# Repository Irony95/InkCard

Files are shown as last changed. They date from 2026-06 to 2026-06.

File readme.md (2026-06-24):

# Introduction
An e-ink display card that mirrors your phone screen, to help with reading documents, e-books, web pages etc!

The project is made to be as cheap as possible, coming to a total cost of around $35USD for materials. This would be even lower if made/bought in bulk!

As this is a prototype and in heavy development, I would not recommend making this unless you're willing to tinker/is familiar with electronics and or app dev.
Nevertheless, If you do want to make the project you are free to do so! I am open to answering any questions should you make the card.
I am also open to the idea of making and selling the hardware itself, though this comes down to if there is interest in the project and when I feel the quality is good enough.

Currently, there is only support for an android app. Check out the repo [here](https://github.com/Irony95/InkCard-androidApp).
I have no experience in IOS development, so I am entirely unsure if an app can even be made for the IOS system. If it is, do let me know!

Any suggestions and support is greatly welcomed.

### Notes when building
1. Use a 11uH receiver coil and connect to AC1 and AC2. feel free to use a different coil if you so wish, with C32-C34 and C15 for tuning. refer to BQ51013 datasheet for more info
2. Bridge both JP1 and JP3 from the middle to pad 3, these help select options for the e-paper driver
3. Adjust/remake the CoilLifter.stl to fit your receiver coil size

### Glam Pics!





### Future 
Although the project was primarily built to be as cheap as possible so to allow anybody to get an e-reader, a future version with touch screen and battery is being considered! This version would likely add significant amounts to the cost, but would likely make the project infinitely better. 
Additional features like auto/partial screen refreshes, manual cropping, custom button functions are also being considered.

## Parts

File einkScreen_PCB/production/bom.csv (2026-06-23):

Designator | Footprint | Quantity | Value | LCSC Part #
C1, C16, C17, C18, C29, C31, C33 | 0805 | 7 | 100nF | C28233
C10, C11, C2, C20, C3, C4, C5, C6, C7, C8, C9 | 0805 | 11 | 1uF | C28323
C12, C13, C27 | 0805 | 3 | 4.7uF | C1779
C14, C19, C28, C30 | 0805 | 4 | 10uF | C15850
C15 | 0805 | 1 | 2.2nF | C28260
C21, C22 | 0805 | 2 | 10nF | C1710
C23, C24 | 0805 | 2 | 470nF | C13967
C25, C26, C34 | 0805 | 3 | 22nF | C1729
C32 | 0805 | 1 | 33nF | C1739
D1, D2, D3 | D_SOD-123 | 3 | MBR0530 | C18863
D4 | 0805 | 1 | LED | C84256
D5 | D_SOD-123 | 1 | 1N5819 | C82544
D6, D7, D8 | D_SOD-923 | 3 | ESD9B5.0ST5G | C111566
J3 | HRS_FH34SRJ-24S-0.5SH_50_ | 1 | FH34SRJ-24S-0.5SH_50_ | C324726
JP2 | TestPoint_2Pads_Pitch2.54mm_Drill0.8mm | 1 | JumperEN
JP4 | TestPoint_2Pads_Pitch2.54mm_Drill0.8mm | 1 | JumperBOOT
L1 | 1210 | 1 | 10uH | C60541
Q1 | TSOT-23 | 1 | A03400 | C20917
Q2, Q4, Q5 | TSOT-23 | 3 | A03401 | C15127
Q3 | TSOT-23 | 1 | S8050 | C2146
R10, R11, R12, R15, R19, R20, R24, R25, R3, R5 | 0805 | 10 | 10K | C17414
R16 | 0805 | 1 | 200 | C17540
R17 | 0805 | 1 | 20K | C4328
R18 | 0805 | 1 | 560R | C28636
R2 | 0805 | 1 | 3R | C17660
R21 | 0805 | 1 | 330R | C17630
R22 | 0805 | 1 | 0R | C17477
R4 | 0805 | 1 | 47K | C17713
R7, R9 | 0805 | 2 | 5.1K | C27834
R8 | 0805 | 1 | 100K | C149504
SW1, SW2 | Panasonic_EVQPUL_EVQPUC | 2 | SW_Push | C79174
TP1 | TestPoint_Pad_D3.0mm | 1 | AC1
TP2 | TestPoint_Pad_D3.0mm | 1 | AC2
U1 | VQFN-20_L4.5-W3.5-P0.50-BL-EP_BQ24100RHLR | 1 | BQ51013BRHLR | C55663
U2 | SOT-23-5 | 1 | XC6220B331MR | C22466451
U3 | WIRELM-SMD_ESP32-C6-WROOM-1 | 1 | ESP32-C6-WROOM-1-N8 | C5366877
USB1 | USB-C-SMD_TYPE-C-16PIN-2MD-073 | 1 | TYPE-C 16PIN 2MD | C2765186

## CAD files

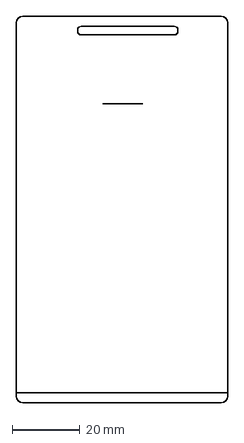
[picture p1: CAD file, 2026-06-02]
einkScreen_PCB/PCBOutline.dxf
62.4 x 113.8 mm

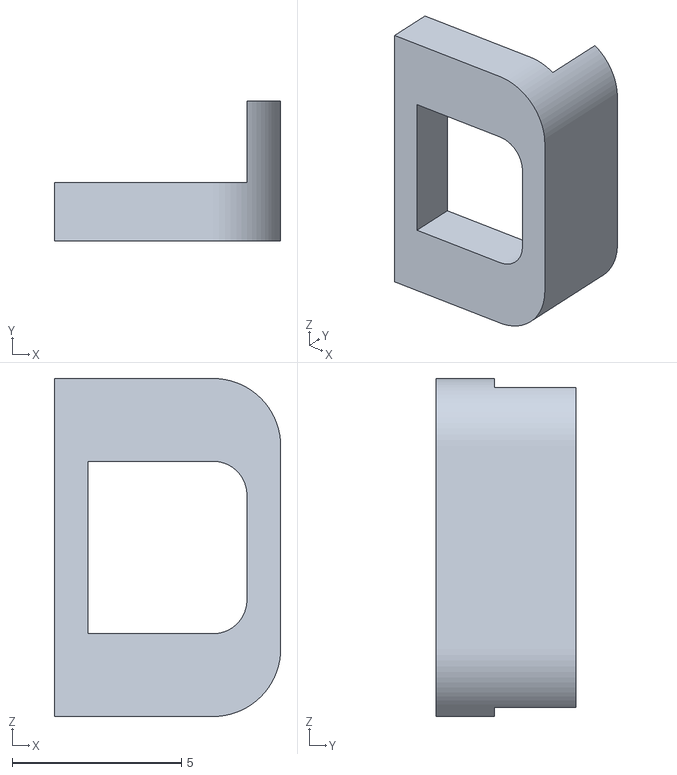
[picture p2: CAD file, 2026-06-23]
inkCard_Case/Button.stl
6.70 x 4.14 x 10.00

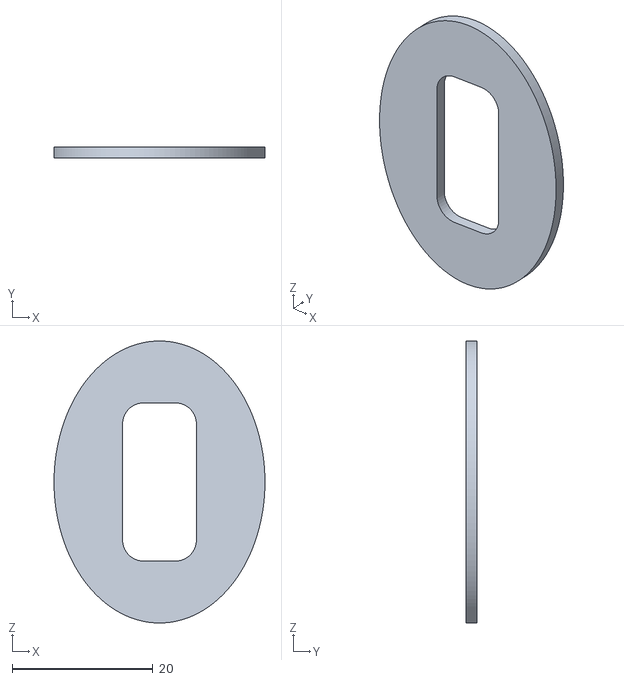
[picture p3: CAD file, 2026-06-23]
inkCard_Case/CoilLifter.stl
30.0 x 1.60 x 40.1

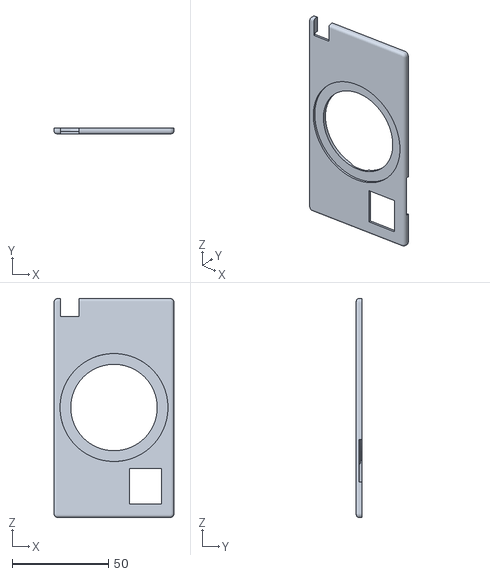
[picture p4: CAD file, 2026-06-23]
inkCard_Case/Body.stl
62.4 x 2.90 x 113.8

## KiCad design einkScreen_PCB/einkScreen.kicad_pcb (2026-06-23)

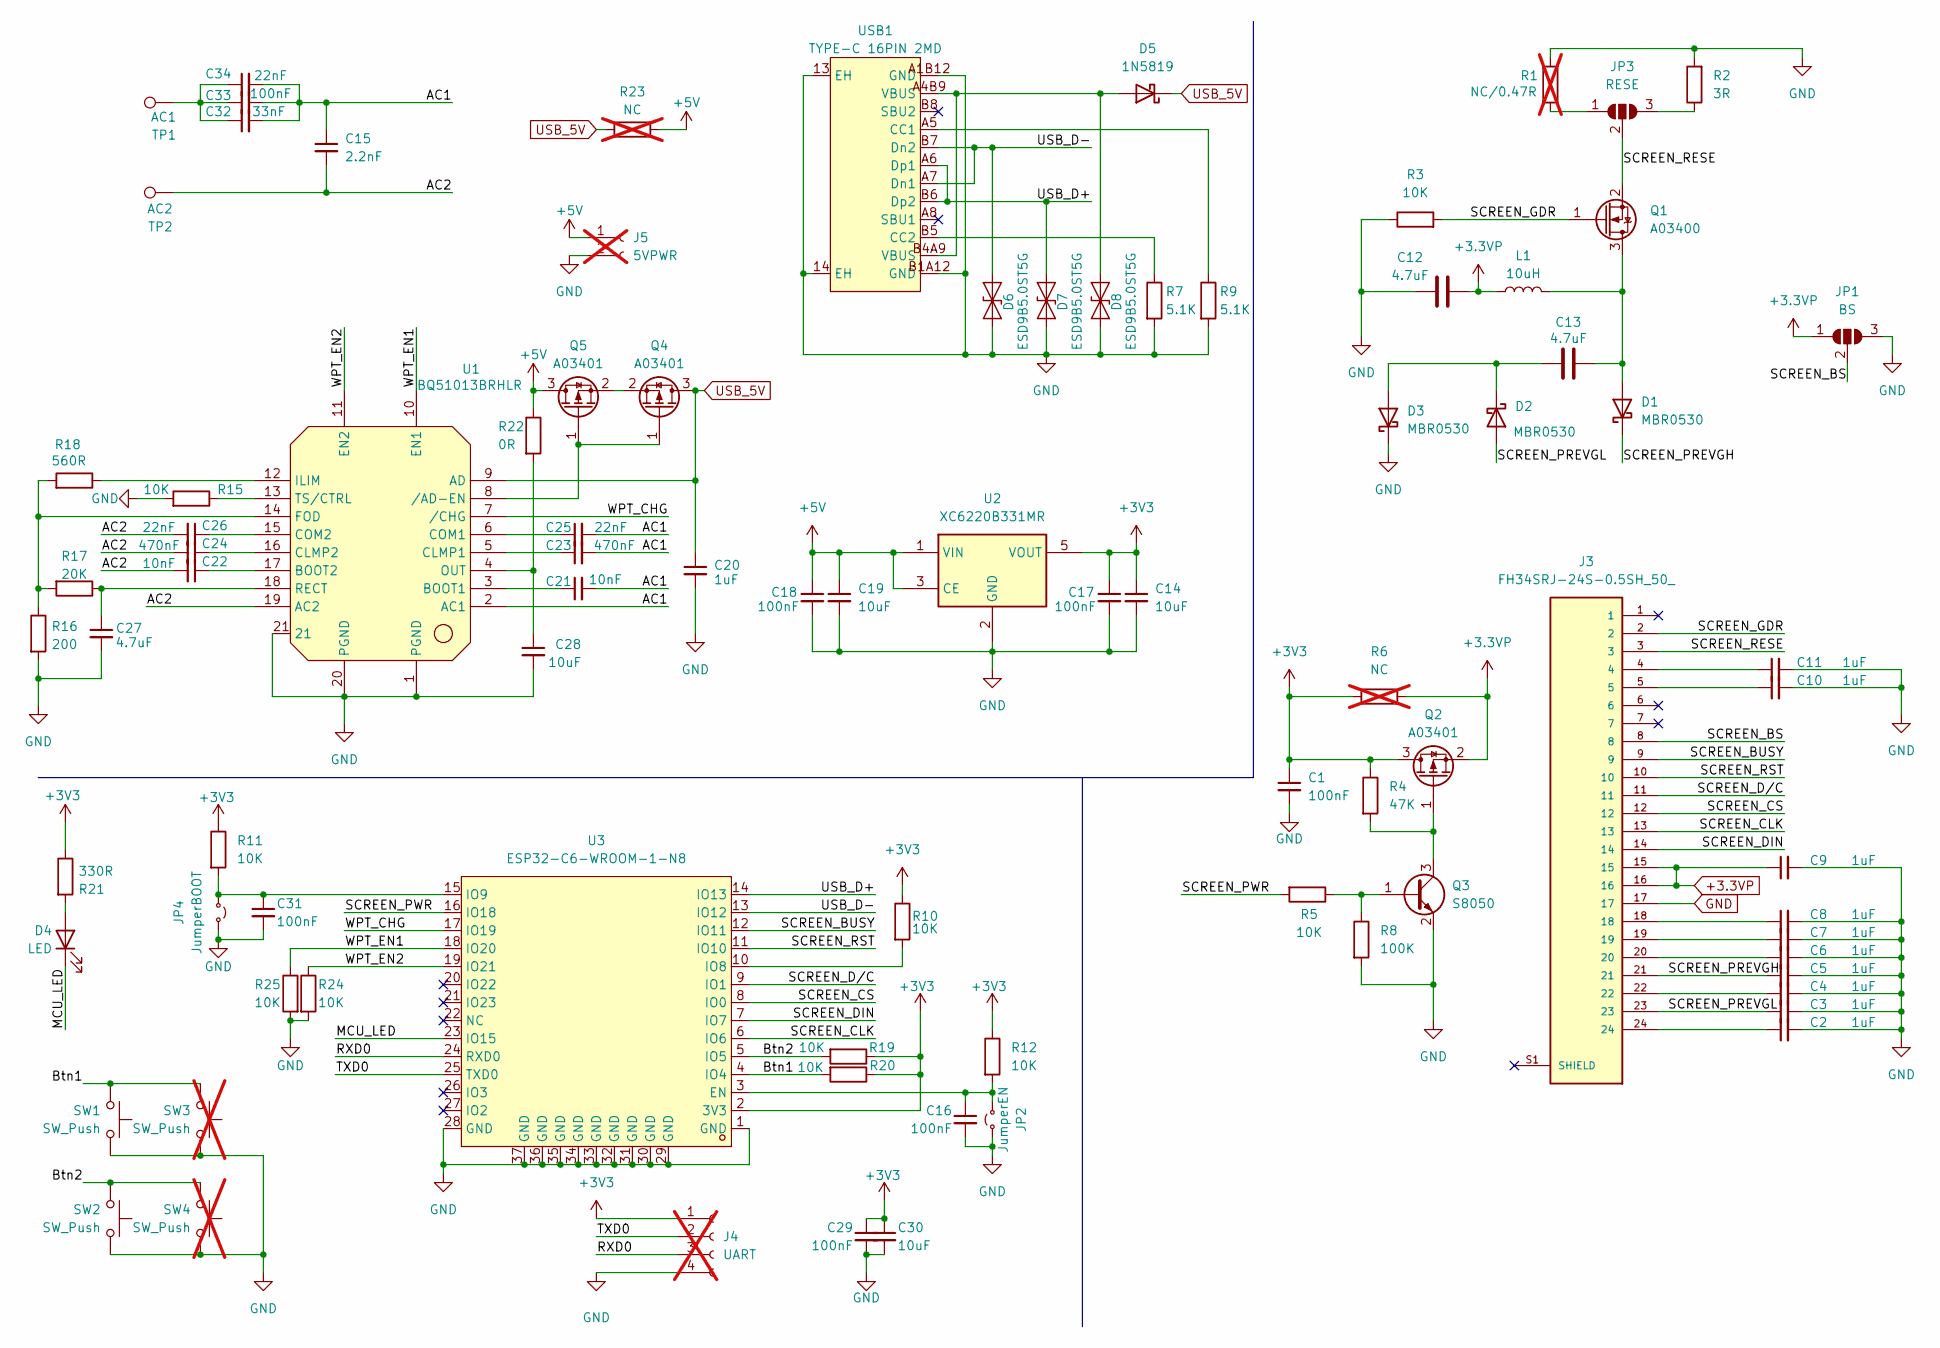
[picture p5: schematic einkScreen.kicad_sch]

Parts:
C1, C16, C17, C18, C29, C31, C33: 100nF; C_0805_2012Metric; LCSC C28233
C2, C3, C4, C5, C6, C7, C8, C9, C10, C11, C20: 1uF; C_0805_2012Metric; LCSC C28323
C12, C13, C27: 4.7uF; C_0805_2012Metric; LCSC C1779
C14, C19, C28, C30: 10uF; C_0805_2012Metric; LCSC C15850
C15: 2.2nF; C_0805_2012Metric; LCSC C28260
C21, C22: 10nF; C_0805_2012Metric; LCSC C1710
C23, C24: 470nF; C_0805_2012Metric; LCSC C13967
C25, C26, C34: 22nF; C_0805_2012Metric; LCSC C1729
C32: 33nF; C_0805_2012Metric; LCSC C1739
D1, D2, D3: MBR0530; D_SOD-123; LCSC C18863
D4: LED; LED_0805_2012Metric; LCSC C84256
D5: 1N5819; D_SOD-123; LCSC C82544
D6, D7, D8: ESD9B5.0ST5G; D_SOD-923; LCSC C111566
J3: FH34SRJ-24S-0.5SH_50_; HRS_FH34SRJ-24S-0.5SH_50_; LCSC C324726
J4: UART; PinSocket_1x04_P2.54mm_Vertical; not fitted
J5: 5VPWR; PinSocket_1x02_P2.54mm_Vertical; not fitted
JP1: BS; SolderJumper-3_P1.3mm_Open_RoundedPad1.0x1.5mm_NumberLabels
JP2: JumperEN; TestPoint_2Pads_Pitch2.54mm_Drill0.8mm
JP3: RESE; SolderJumper-3_P1.3mm_Open_RoundedPad1.0x1.5mm_NumberLabels
JP4: JumperBOOT; TestPoint_2Pads_Pitch2.54mm_Drill0.8mm
L1: 10uH; L_1210_3225Metric; LCSC C60541
Q1: A03400; TSOT-23; LCSC C20917
Q2, Q4, Q5: A03401; TSOT-23; LCSC C15127
Q3: S8050; TSOT-23; LCSC C2146
R1: NC/0.47R; R_0805_2012Metric; not fitted
R2: 3R; R_0805_2012Metric; LCSC C17660
R3, R5, R10, R11, R12, R15, R19, R20, R24, R25: 10K; R_0805_2012Metric; LCSC C17414
R4: 47K; R_0805_2012Metric; LCSC C17713
R6, R23: NC; R_0805_2012Metric; not fitted
R7, R9: 5.1K; R_0805_2012Metric; LCSC C27834
R8: 100K; R_0805_2012Metric; LCSC C149504
R16: 200; R_0805_2012Metric; LCSC C17540
R17: 20K; R_0805_2012Metric; LCSC C4328
R18: 560R; R_0805_2012Metric; LCSC C28636
R21: 330R; R_0805_2012Metric; LCSC C17630
R22: 0R; R_0805_2012Metric; LCSC C17477
SW1, SW2: SW_Push; Panasonic_EVQPUL_EVQPUC; LCSC C79174
SW3, SW4: SW_Push; KEY-SMD_L4.0-W3.0-LS4.9-1; not fitted
TP1: AC1; TestPoint_Pad_D3.0mm
TP2: AC2; TestPoint_Pad_D3.0mm
U1: BQ51013BRHLR; VQFN-20_L4.5-W3.5-P0.50-BL-EP_BQ24100RHLR; MPN BQ51013BRHLR; LCSC Part C55663
U2: XC6220B331MR; SOT-23-5; LCSC C22466451
U3: ESP32-C6-WROOM-1-N8; WIRELM-SMD_ESP32-C6-WROOM-1; MPN ESP32-C6-WROOM-1-N8; LCSC Part C5366877
USB1: TYPE-C 16PIN 2MD; USB-C-SMD_TYPE-C-16PIN-2MD-073; MPN TYPE-C 16PIN 2MD(073); LCSC Part C2765186

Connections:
+3.3VP: C9.1, C12.2, J3.15, J3.16, JP1.1 (A), L1.1, Q2.2 (S), R6.2
+3V3: C1.1, C14.1, C17.1, C29.1, C30.1, J4.1, Q2.3 (D), R4.1, R6.1, R10.1, R11.1, R12.1, R19.1, R20.1, R21.1, U2.5 (VOUT), U3.2 (3V3)
+5V: C18.1, C19.1, J5.1, Q5.3 (D), R22.1, R23.2, U2.1 (VIN), U2.3 (CE)
/AC1: C15.1, C21.2, C23.2, C25.2, C32.2, C33.2, C34.2, U1.2 (AC1)
/AC2: C15.2, C22.2, C24.2, C26.2, TP2.1 (1_1), U1.19 (AC2)
/Btn1: R20.2, SW1.2, SW3.2, U3.4 (IO4)
/Btn2: R19.2, SW2.2, SW4.2, U3.5 (IO5)
/MCU_LED: D4.1 (K), U3.23 (IO15)
/RXD0: J4.3, U3.24 (RXD0)
/SCREEN_BS: J3.8, JP1.2 (C)
/SCREEN_BUSY: J3.9, U3.12 (IO11)
/SCREEN_CLK: J3.13, U3.6 (IO6)
/SCREEN_CS: J3.12, U3.8 (IO0)
/SCREEN_DIN: J3.14, U3.7 (IO7)
/SCREEN_D/C: J3.11, U3.9 (IO1)
/SCREEN_GDR: J3.2, Q1.1 (G), R3.2
/SCREEN_PREVGH: C5.1, D1.1 (K), J3.21
/SCREEN_PREVGL: C3.1, D2.2 (A), J3.23
/SCREEN_PWR: R5.2, U3.16 (IO18)
/SCREEN_RESE: J3.3, JP3.2 (C), Q1.2 (S)
/SCREEN_RST: J3.10, U3.11 (IO10)
/TXD0: J4.2, U3.25 (TXD0)
/USB_D+: D7.2 (A2), U3.14 (IO13), USB1.A6 (Dp1), USB1.B6 (Dp2)
/USB_D-: D6.2 (A2), U3.13 (IO12), USB1.A7 (Dn1), USB1.B7 (Dn2)
/WPT_CHG: U1.7 (/CHG), U3.17 (IO19)
/WPT_EN1: R25.1, U1.10 (EN1), U3.18 (IO20)
/WPT_EN2: R24.1, U1.11 (EN2), U3.19 (IO21)
GND: C1.2, C2.2, C3.2, C4.2, C5.2, C6.2, C7.2, C8.2, C9.2, C10.2, C11.2, C12.1, C14.2, C16.2, C17.2, C18.2, C19.2, C20.2, C27.2, C28.2, C29.2, C30.2, C31.2, D3.1 (K), D6.1 (A1), D7.1 (A1), D8.1 (A1), J3.17, J4.4, J5.2, JP1.3 (B), JP2.2 (B), JP4.2 (B), Q3.2 (E), R1.1, R2.2, R3.1, R7.2, R8.2, R9.2, R15.2, R16.2, R24.2, R25.2, SW1.1, SW2.1, SW3.1, SW4.1, U1.1 (PGND), U1.20 (PGND), U1.21, U2.2 (GND), U3.1 (GND), U3.28 (GND), U3.29 (GND), U3.30 (GND), U3.31 (GND), U3.32 (GND), U3.33 (GND), U3.34 (GND), U3.35 (GND), U3.36 (GND), U3.37 (GND), USB1.13 (EH), USB1.14 (EH), USB1.A1B12 (GND), USB1.B1A12 (GND)
unnamed: C2.1, J3.24
unnamed: C4.1, J3.22
unnamed: C6.1, J3.20
unnamed: C7.1, J3.19
unnamed: C8.1, J3.18
unnamed: C10.1, J3.5
unnamed: C11.1, J3.4
unnamed: C32.1, C33.1, C34.1, TP1.1 (1_1)
unnamed: C13.2, D1.2 (A), L1.2, Q1.3 (D)
unnamed: C13.1, D2.1 (K), D3.2 (A)
unnamed: D4.2 (A), R21.2
unnamed: D5.2 (A), D8.2 (A2), USB1.A4B9 (VBUS), USB1.B4A9 (VBUS)
unnamed: C16.1, JP2.1 (A), R12.2, U3.3 (EN)
unnamed: JP3.1 (A), R1.2
unnamed: JP3.3 (B), R2.1
unnamed: C31.1, JP4.1 (A), R11.2, U3.15 (IO9)
unnamed: Q2.1 (G), Q3.3 (C), R4.2
unnamed: Q3.1 (B), R5.1, R8.1
unnamed: Q4.1 (G), Q5.1 (G), U1.8 (/AD-EN)
unnamed: Q4.2 (S), Q5.2 (S)
unnamed: C21.1, U1.3 (BOOT1)
unnamed: C22.1, U1.17 (BOOT2)
unnamed: C23.1, U1.5 (CLMP1)
unnamed: C24.1, U1.16 (CLMP2)
unnamed: C25.1, U1.6 (COM1)
unnamed: C26.1, U1.15 (COM2)
unnamed: R16.1, R17.2, R18.2, U1.14 (FOD)
unnamed: R18.1, U1.12 (ILIM)
unnamed: C28.1, R22.2, U1.4 (OUT)
unnamed: C27.1, R17.1, U1.18 (RECT)
unnamed: R15.1, U1.13 (TS/CTRL)
unnamed: R10.2, U3.10 (IO8)
unnamed: R9.1, USB1.A5 (CC1)
unnamed: R7.1, USB1.B5 (CC2)
USB_5V: C20.1, D5.1 (K), Q4.3 (D), R23.1, U1.9 (AD)

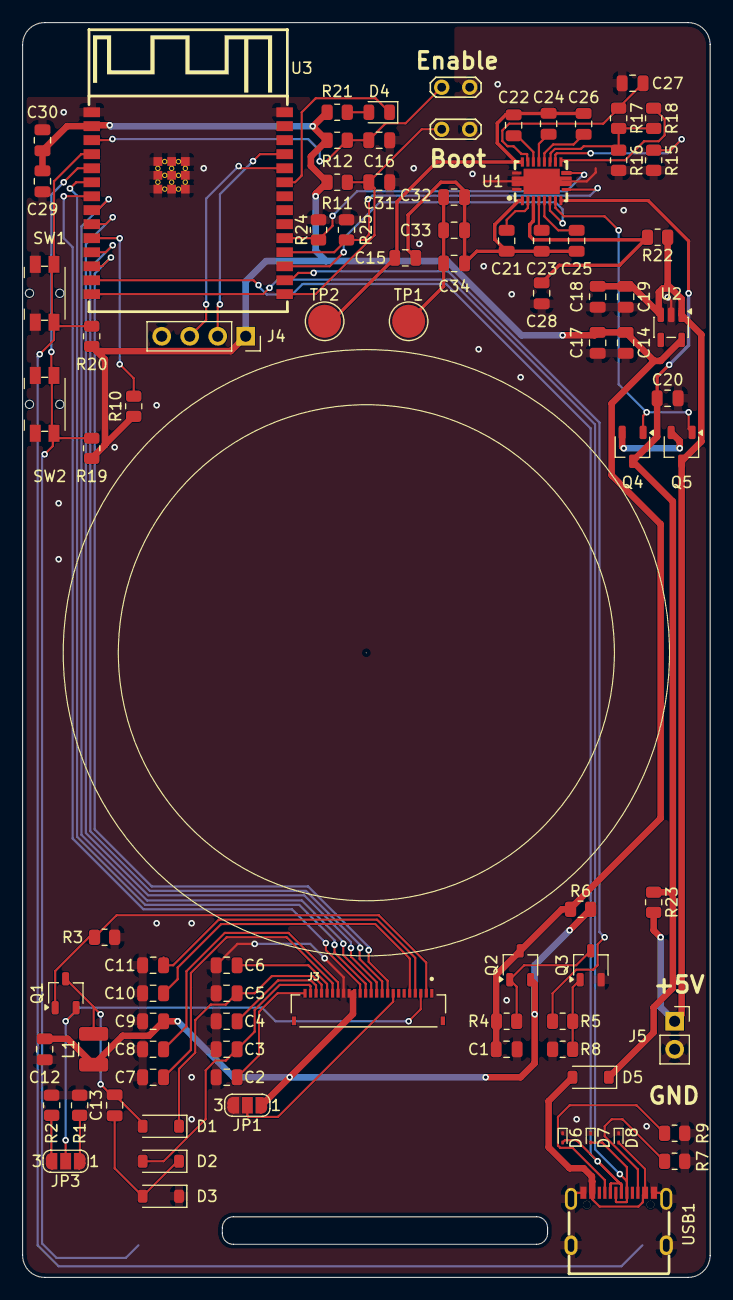
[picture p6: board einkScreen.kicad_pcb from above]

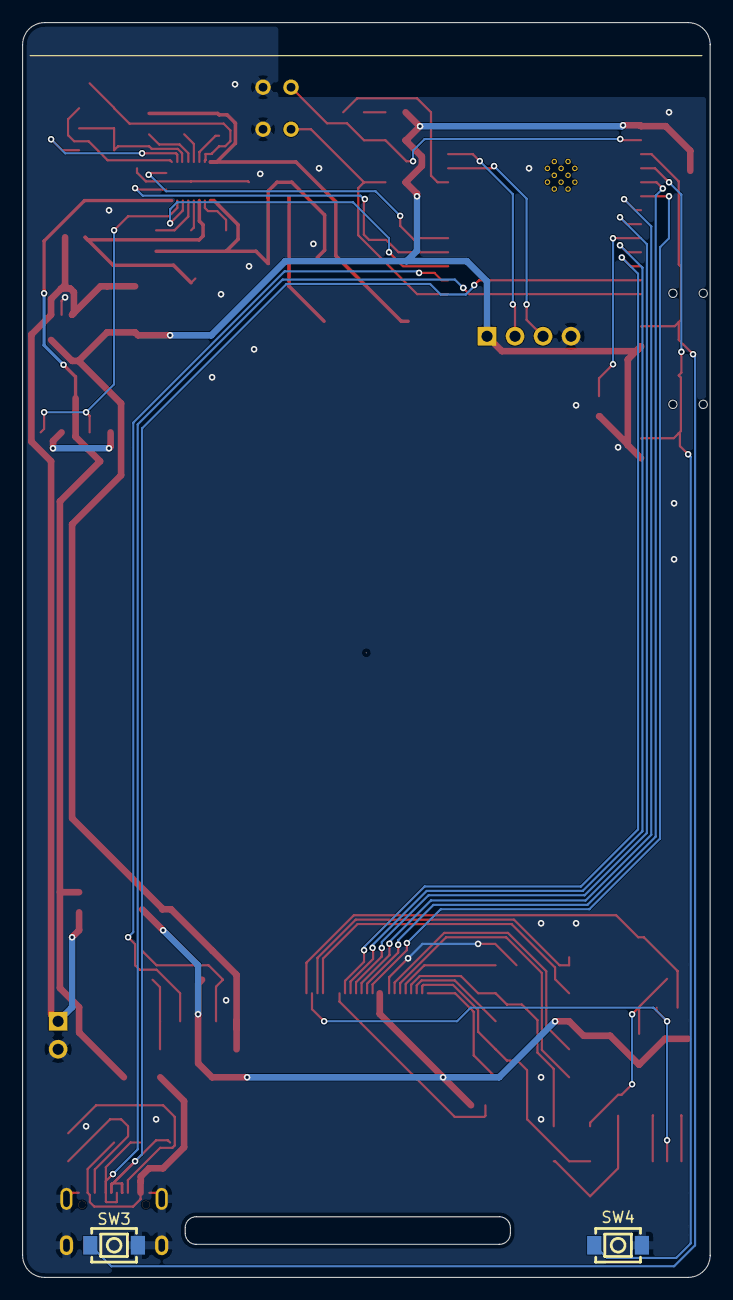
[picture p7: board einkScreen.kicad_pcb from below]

Board: 2 copper layers, 62.4 x 113.8 mm, 88 parts (2 on the bottom side), 63 nets.

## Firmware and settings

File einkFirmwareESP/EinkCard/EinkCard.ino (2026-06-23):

#include <Arduino.h>

#include <BLEDevice.h>
#include <BLEUtils.h>
#include <BLEServer.h>

#include <SPI.h>
#include "epd4in26.h"
#include <BLE2902.h>

#define BTN_1 4
#define BTN_2 5
#define LED_PIN 15 

// BLE Device Name
#define SERVER_NAME "Eink Card"

// Custom UUIDs
#define SERVICE_UUID "00000000-0000-0000-0000-000000000000"

#define IMAGE_UUID "cba1d466-344c-4be3-ab3f-189f80dd7518"
#define BTN1_UUID "f78ebbff-c8b7-4107-93de-889a6a06d408"
#define BTN2_UUID "ca73b3ba-39f6-4ab3-91ae-186dc9577d99"

#define WIDTH_UUID "27440532-c615-4a43-bbba-2e0ee40327c2"
#define HEIGHT_UUID "12e9f06a-9c60-4430-bf43-8da3603fa765"

#define COMM_TIMEOUT 2000


BLEServer *bleServer;

BLECharacteristic *bleImage;
BLECharacteristic *bleButton1;
BLECharacteristic *bleButton2;

BLECharacteristic *widthChar;
BLECharacteristic *heightChar;

bool btn1Pressed = false, btn2Pressed = false;
int lastIntr = 0;
bool deviceConnected = false;

unsigned long startChunkTime = millis();

Epd epd;

void IRAM_ATTR btn1Interrupt()
{ 
  if ( millis() - lastIntr < 500) { return; }
  btn1Pressed = true;
  lastIntr = millis();
}

void IRAM_ATTR btn2Interrupt()
{
  if ( millis() - lastIntr < 500) { return; }
  btn2Pressed = true;
  lastIntr = millis();
}
enum ImageUpdateType {
  NONE = 0,
  BLACK_WHITE_FAST = 1,
  BLACK_WHITE = 2,
  FOUR_GRAY_REG_ONE = 3,
  FOUR_GRAY_REG_TWO = 4,
  PARTIAL = 5,
};

enum ImageUpdateType imageUpdating = NONE;
u_int imageBytesToSend = 0;
void setupBLE();

class ImageCharCallback: public BLECharacteristicCallbacks {  
    void onWrite(BLECharacteristic *pCharacteristic) {          
      uint8_t *arr = pCharacteristic->getData();
      int arrLen = pCharacteristic->getLength();            

      //receiving new image
      if (imageUpdating == NONE || arrLen == 1)
      {
        imageUpdating = (ImageUpdateType)arr[0];
        startChunkTime = millis();

        switch (imageUpdating)
        {
        case BLACK_WHITE_FAST:          
        case BLACK_WHITE:
          epd.SendCommand(0x24);
          imageBytesToSend = (EPD_HEIGHT * EPD_WIDTH)/8;
          break;

        case FOUR_GRAY_REG_ONE:          
          epd.SendCommand(0x24);
          imageBytesToSend = (EPD_HEIGHT * EPD_WIDTH)/8;
          break;

        case FOUR_GRAY_REG_TWO:          
          epd.SendCommand(0x26);
          imageBytesToSend = (EPD_HEIGHT * EPD_WIDTH)/8;
          break;
        case PARTIAL:
          epd.SendCommand(0x24);
          imageBytesToSend = (EPD_HEIGHT * EPD_WIDTH)/8;
        
        default:
          break;
        }
      }
      else
      {
        for (int i = 0;i < arrLen;i++)
        { epd.SendData(arr[i]); }
        if (imageBytesToSend < arrLen) {imageBytesToSend = 0; }
        else { imageBytesToSend -= arrLen; }        
      }   
    }
};

class MyServerCallbacks: public BLEServerCallbacks {
  void onConnect(BLEServer* pServer) {
    Serial.println("connected to a device");
    deviceConnected = true;
    bleServer->getAdvertising()->stop();
    
  };
  void onDisconnect(BLEServer* pServer) {
    Serial.println("disconnected");
    deviceConnected = false;
    bleServer->getAdvertising()->start();
  }

  void onMtuChanged(BLEServer* pServer)
  {
    Serial.print("mtu updated");
  }
};

void setupBLE() {
  BLEDevice::init(SERVER_NAME);
  BLEDevice::setMTU(517);
  bleServer = BLEDevice::createServer();  
  bleServer->setCallbacks(new MyServerCallbacks());

  BLEService *service = bleServer->createService(SERVICE_UUID);
  bleImage = service->createCharacteristic(
    IMAGE_UUID,
    BLECharacteristic::PROPERTY_READ | BLECharacteristic::PROPERTY_WRITE
  );
  bleImage->setCallbacks(new ImageCharCallback());

  bleButton1 = service->createCharacteristic(
    BTN1_UUID,
    BLECharacteristic::PROPERTY_READ | BLECharacteristic::PROPERTY_WRITE | BLECharacteristic::PROPERTY_NOTIFY
  );
  bleButton1->addDescriptor(new BLE2902());

  
  bleButton2 = service->createCharacteristic(
    BTN2_UUID,
    BLECharacteristic::PROPERTY_READ | BLECharacteristic::PROPERTY_WRITE | BLECharacteristic::PROPERTY_NOTIFY
  );
  bleButton2->addDescriptor(new BLE2902());
  
  widthChar = service->createCharacteristic(
    WIDTH_UUID,
    BLECharacteristic::PROPERTY_READ
  );
  widthChar->setValue(String(EPD_WIDTH).c_str());

  heightChar = service->createCharacteristic(
    HEIGHT_UUID,
    BLECharacteristic::PROPERTY_READ
  );
  heightChar->setValue(String(EPD_HEIGHT).c_str());

  service->start();
  BLEAdvertising *advertising = BLEDevice::getAdvertising();
  advertising->addServiceUUID(SERVICE_UUID);
  bleServer->getAdvertising()->start(); 
}

void setup()
{
  
  Serial.begin(115200);    
  Serial.println("startign");

  pinMode(BTN_1, INPUT_PULLUP);
  attachInterrupt(BTN_1, btn1Interrupt, RISING);
  pinMode(BTN_2, INPUT_PULLUP);
  attachInterrupt(BTN_2, btn2Interrupt, RISING);

  pinMode(LED_PIN, OUTPUT);
  digitalWrite(LED_PIN, LOW);

  setupBLE();
  if (epd.Init() != 0) {
    Serial.print("e-Paper init failed");
    return;
  }
  digitalWrite(LED_PIN, HIGH);

  Serial.println("all ok!");
}

int a = 0;
void loop()
{   
  //skip if device is not connected
  if (!deviceConnected)
  {
    Serial.println("device not connected");
    digitalWrite(LED_PIN, LOW);
    delay(500);
    digitalWrite(LED_PIN, HIGH);
    delay(500);
    return;
  }

  if (btn1Pressed)
  {
    btn1Pressed = false;
    Serial.println("button 1 pressed");        
    bleButton1->notify();
    a++;
  }
  else if (btn2Pressed)
  {
    btn2Pressed = false;
    Serial.println("button 2 pressed");    
    bleButton2->notify();
    a++;
  }  


  //received all the bytes for the image
  if (imageBytesToSend == 0 && imageUpdating != NONE)
  {
    Serial.println("refreshing");
    switch (imageUpdating)
    {
    case BLACK_WHITE_FAST:
      Serial.println("BW FAST");
      imageUpdating = NONE;
      epd.Set_Fast();        
      epd.TurnOnDisplay_Fast();
      break;
      
    case BLACK_WHITE:
      Serial.println("BW");
      imageUpdating = NONE;
      epd.TurnOnDisplay(); 
      break;

    case FOUR_GRAY_REG_ONE:
      imageUpdating = NONE;
      Serial.println("REG ONE");
      break;

    case FOUR_GRAY_REG_TWO:
      imageUpdating = NONE;
      Serial.println("GRAYSCALE");
      epd.Set_4Gray();
      epd.TurnOnDisplay_4GRAY();
      break;

    case PARTIAL:
      //TODO: Not yet tested
      Serial.println("Partial");
      imageUpdating = NONE;
      epd.TurnOnDisplay_Part();
      break;
    
    default:
      imageUpdating = NONE;
      break;
    }
  }
  else if (imageBytesToSend > 0 && imageUpdating != NONE && millis() - startChunkTime > COMM_TIMEOUT)
  {
    Serial.println("Receive timeout!");    
    imageBytesToSend = 0;
    imageUpdating = NONE;
  }
  delay(50);
}

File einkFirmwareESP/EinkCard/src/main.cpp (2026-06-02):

#include <Arduino.h>

#include <BLEDevice.h>
#include <BLEUtils.h>
#include <BLEServer.h>

#include <SPI.h>
#include "epd4in26.h"

#define BTN_1 22
#define BTN_2 21

#define COMMS_CHUNK_SIZE 511
#define COMMS_OK 0xFF

// BLE Device Name
#define SERVER_NAME "Eink Card"

// Custom UUIDs
#define SERVICE_UUID "00000000-0000-0000-0000-000000000000"

#define IMAGE_UUID "cba1d466-344c-4be3-ab3f-189f80dd7518"
#define BTN1_UUID "f78ebbff-c8b7-4107-93de-889a6a06d408"
#define BTN2_UUID "ca73b3ba-39f6-4ab3-91ae-186dc9577d99"


//Address of the peripheral device. Address will be found during scanning...
BLEServer *bleServer;

BLECharacteristic *bleImage;
BLECharacteristic *bleButton1;
BLECharacteristic *bleButton2;
bool btn1Pressed = false, btn2Pressed = false;
int lastIntr = 0;
bool deviceConnected = false; 

Epd epd;

void IRAM_ATTR btn1Interrupt()
{ 
  if ( millis() - lastIntr < 100) { return; }
  btn1Pressed = true;
  lastIntr = millis();
}

void IRAM_ATTR btn2Interrupt()
{
  if ( millis() - lastIntr < 100) { return; }
  btn2Pressed = true;
  lastIntr = millis();
}

u_int imageSize = 0;
u_int receivedByteCount = 0;
//max image buffer, with 4 color grayscale
// uint8_t imageBuffer[4] = {0};

void getStatusBytes(float voltage, bool btn1, bool btn2, uint8_t *statusByte);
float readVcc();
void setupBLE();

class MyCallbacks: public BLECharacteristicCallbacks {
    void onWrite(BLECharacteristic *pCharacteristic, esp_ble_gatts_cb_param_t* param) {      
      uint8_t *arr = pCharacteristic->getData();
      int arrLen = pCharacteristic->getLength();      
      //received size of image
      if (imageSize == 0)
      {        
        memcpy(&imageSize, arr, arrLen);        
        Serial.println("receiving start");
        epd.SendCommand(0x24);
      }
      else if (receivedByteCount < imageSize)
      {        
        for (int i = 0;i < arrLen;i++)
        { epd.SendData(arr[i]); }
        receivedByteCount += arrLen;
      }
    }
};

class MyServerCallbacks: public BLEServerCallbacks {
  void onConnect(BLEServer* pServer) {
    Serial.println("connected to a device");
    deviceConnected = true;
    bleServer->getAdvertising()->stop();
    
  };
  void onDisconnect(BLEServer* pServer) {
    Serial.println("disconnected");
    deviceConnected = false;
    bleServer->getAdvertising()->start();
  }

  void onMtuChanged(BLEServer* pServer, esp_ble_gatts_cb_param_t* param)
  {
    Serial.print("mtu updated");
  }
};

void setupBLE() {
  BLEDevice::init(SERVER_NAME);
  BLEDevice::setMTU(517);
  bleServer = BLEDevice::createServer();  
  bleServer->setCallbacks(new MyServerCallbacks());

  BLEService *service = bleServer->createService(SERVICE_UUID);
  bleImage = service->createCharacteristic(
    IMAGE_UUID,
    BLECharacteristic::PROPERTY_READ | BLECharacteristic::PROPERTY_WRITE);
  bleImage->setCallbacks(new MyCallbacks());  
  bleImage->setValue("test");  

  bleButton1 = service->createCharacteristic(
    BTN1_UUID,
    BLECharacteristic::PROPERTY_READ | BLECharacteristic::PROPERTY_WRITE | BLECharacteristic::PROPERTY_NOTIFY
  );
  bleButton2 = service->createCharacteristic(
    BTN2_UUID,
    BLECharacteristic::PROPERTY_READ | BLECharacteristic::PROPERTY_WRITE | BLECharacteristic::PROPERTY_NOTIFY
  );

  service->start();
  BLEAdvertising *advertising = BLEDevice::getAdvertising();
  advertising->addServiceUUID(SERVICE_UUID);
  bleServer->getAdvertising()->start(); 
}

void setup()
{
  
  Serial.begin(115200);    
  Serial.println("startign");

  pinMode(BTN_1, INPUT_PULLUP);
  attachInterrupt(BTN_1, btn1Interrupt, RISING);
  pinMode(BTN_2, INPUT_PULLUP);
  attachInterrupt(BTN_2, btn2Interrupt, RISING);

  if (epd.Init() != 0) {
    Serial.print("e-Paper init failed");
    return;
  }
  epd.Clear();  

  epd.SendCommand(0x24);
  for (int i = 0;i < 480*100;i++)
  {
    epd.SendData(0xF0);
  }
  epd.TurnOnDisplay();



  setupBLE();
  Serial.println("all ok!");
}


void loop()
{   
  //skip if device is not connected
  if (!deviceConnected)
  {
    Serial.println("device not connected");
    delay(1000);
  }

  if (btn1Pressed)
  {
    btn1Pressed = false;
    Serial.println("button 1 pressed");        
    bleButton1->notify();
  }
  else if (btn2Pressed)
  {
    btn2Pressed = false;
    Serial.println("button 2 pressed");    
    bleButton2->notify();
  }  

  //received all the bytes for the image
  if (imageSize != 0 && receivedByteCount >= imageSize)
  {
    Serial.println("refreshing");
    epd.TurnOnDisplay_Part();

    receivedByteCount = 0;
    imageSize = 0;
  }
  delay(50);
}

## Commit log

2026-04-18 nfc version
    [bom.csv, designators.csv, einkScreen.kicad_pcb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]
2026-05-25 working BLE
    [einkScreen.kicad_pcb, einkScreen.kicad_sch]
2026-06-02 working kinda
    [PCBOutline.dxf, bom.csv, designators.csv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]
2026-06-20 still working
    [einkScreen.kicad_pcb, einkScreen.kicad_sch]
2026-06-23 fixed card issues
    [einkScreen.kicad_pcb, einkScreen.kicad_sch]
2026-06-23 added simple readme.md file
    [Body.stl, Button.stl, CoilLifter.stl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]
